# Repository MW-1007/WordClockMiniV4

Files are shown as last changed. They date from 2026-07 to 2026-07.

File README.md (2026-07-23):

# WordClock Mini V4

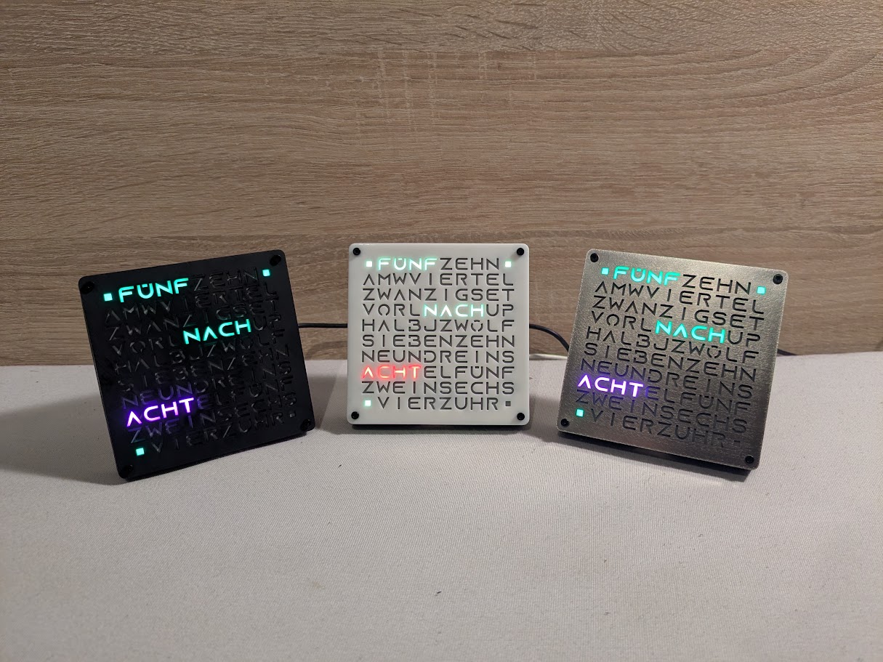
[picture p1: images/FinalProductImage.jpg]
Finished Clock


A fully custom ESP32-C3 based word clock designed and developed from scratch, including firmware, PCB design, web configuration interface, and enclosure integration.

The clock displays the current time using illuminated words in a custom designed font instead of digits and automatically synchronizes with internet time servers. Configuration is handled through a built-in responsive web interface without requiring firmware modifications.

The clock comes in 3 color variants: white, black and stainless steel





---

## Demo Videos

### Quick Demo

Quick Demo (https://github.com/user-attachments/assets/9098f4e6-2d19-4a4c-b324-8256ea519b5b)

### Making Of

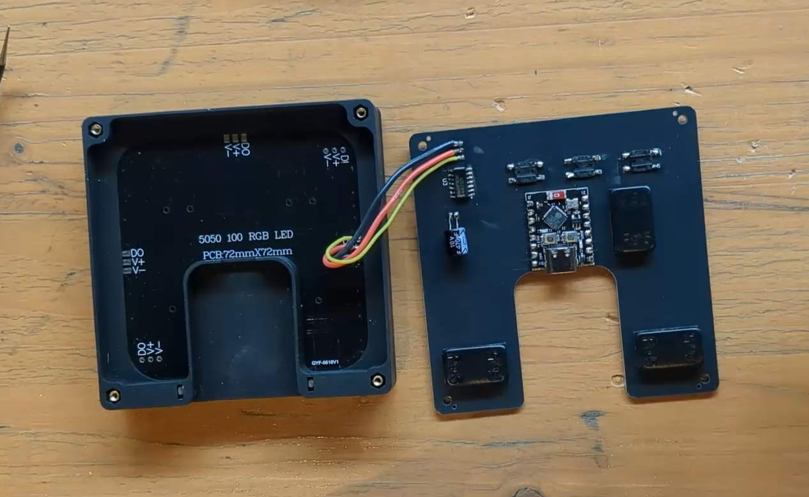
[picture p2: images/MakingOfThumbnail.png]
Making Of (https://github.com/user-attachments/assets/e9385548-6b87-468d-ab12-bdd79818bf12)


### Exploded CAD View

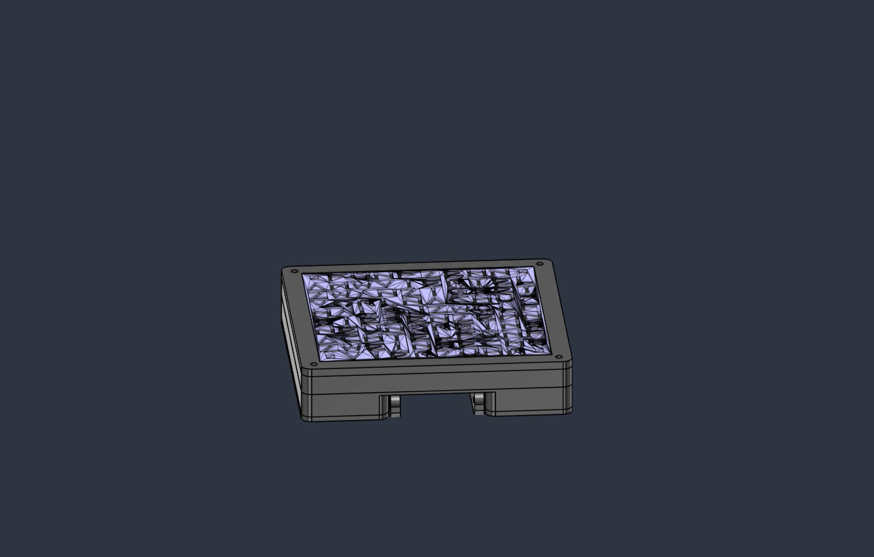
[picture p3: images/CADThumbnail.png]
CAD VIEW (https://github.com/user-attachments/assets/40dce6b3-5bbd-4252-9d69-452dc92e81c9)


---

## Gallery

### Custom PCB

<p align="center">
  PCB Front
  PCB Back
</p>

### CAD-Model built in Fusion

<p align="center">
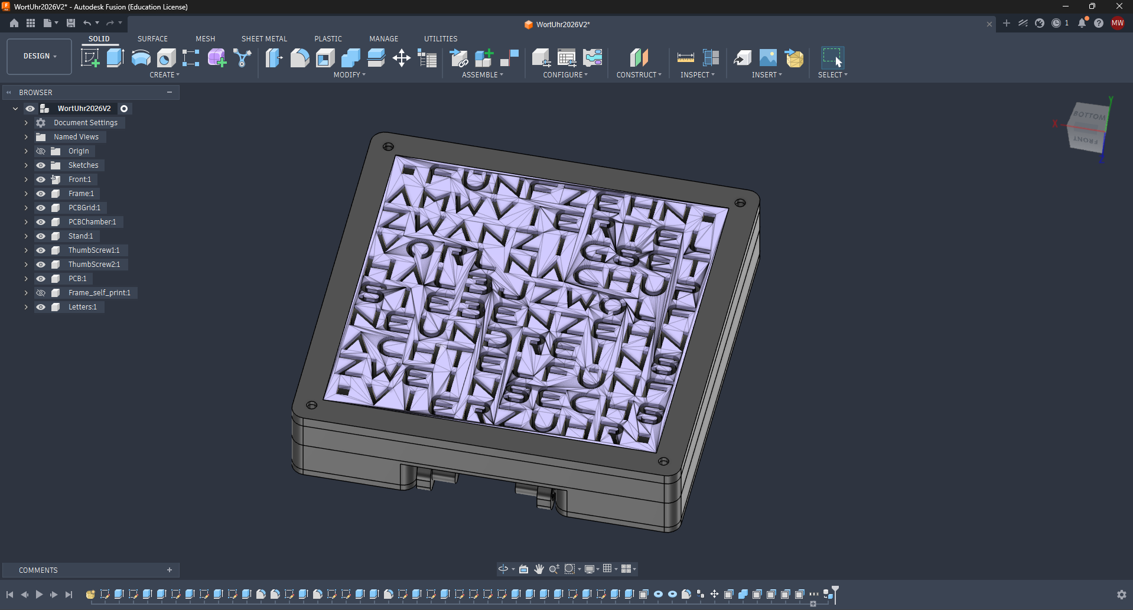
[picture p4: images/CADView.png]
CAD-Model
  
</p>

### Built-in Configuration Interface

<p align="center">
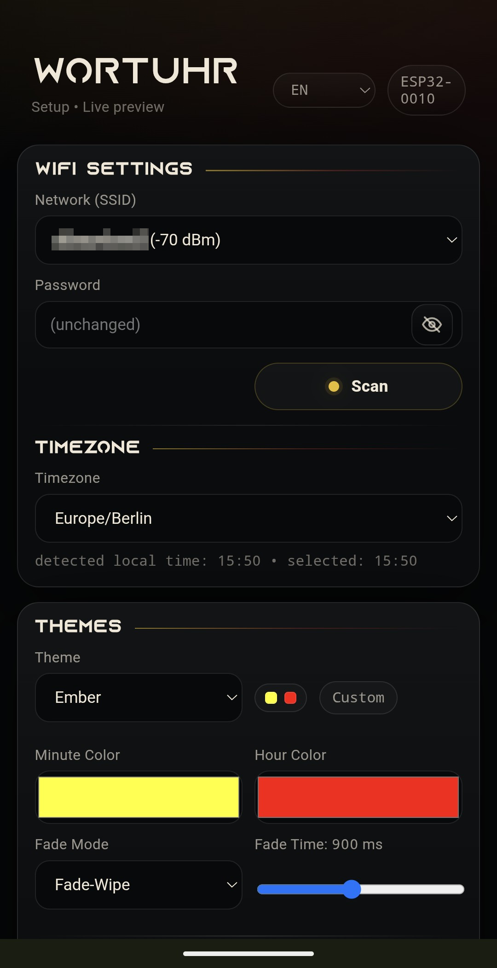
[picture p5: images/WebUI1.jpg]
WebUI
  
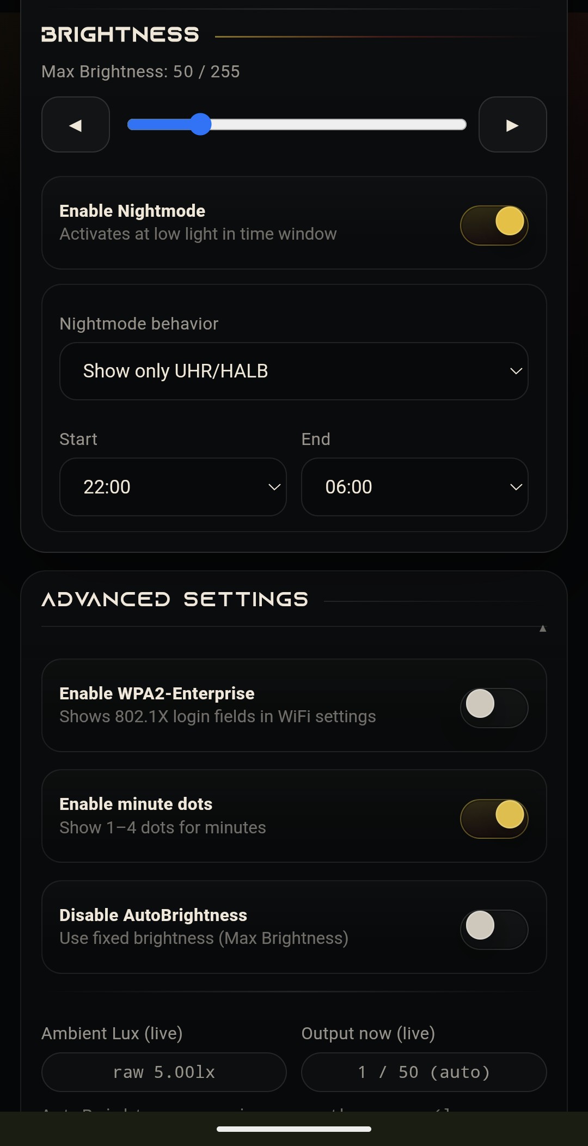
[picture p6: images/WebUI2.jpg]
WebUI
  
</p>

---

## Design Goals

The project was designed with the following goals in mind:

- Compact desktop-sized form factor
- Simple Wi-Fi based configuration / also support WPA-Enterprise
- Automatic brightness adjustment
- No dedicated mobile application required
- Wireless firmware updates
- High-quality visual appearance
- Fully custom hardware platform
- Custom packaging and user manual

---

## Features

* ESP32-C3 based architecture
* Custom PCB design
* Wi-Fi provisioning and configuration portal
* NTP time synchronization
* OTA firmware updates
* Ambient light sensing with automatic brightness control
* Multiple color themes
* Smooth LED transition animations
* Night mode
* Responsive web configuration interface

---

## Mechanical Design

The front face is manufactured using a custom stainless steel SMT stencil,
creating crisp and highly accurate lettering while maintaining a premium appearance.

The enclosure consists of multiple custom-designed 3D printed parts,
including the front frame, PCB chamber and mounting hardware.

A frosted diffuser layer is used to achieve uniform illumination
and eliminate visible LED hotspots.

---

## Hardware

| Component | Purpose |
|---|---|
| ESP32-C3 | Main microcontroller |
| WS2812 LED Matrix | Time display |
| BH1750 | Ambient light sensing |
| SN74AHCT125 | Level shifting for LED data signal |
| Custom PCB | Hardware integration |
| Frosted Diffuser | Uniform light distribution |
| 3D Printed Enclosure | Mechanical assembly |
| USB-C | Power and firmware flashing |
| Tactile Buttons | Setup and user interaction |

---

## License

This project is released under the MIT License.

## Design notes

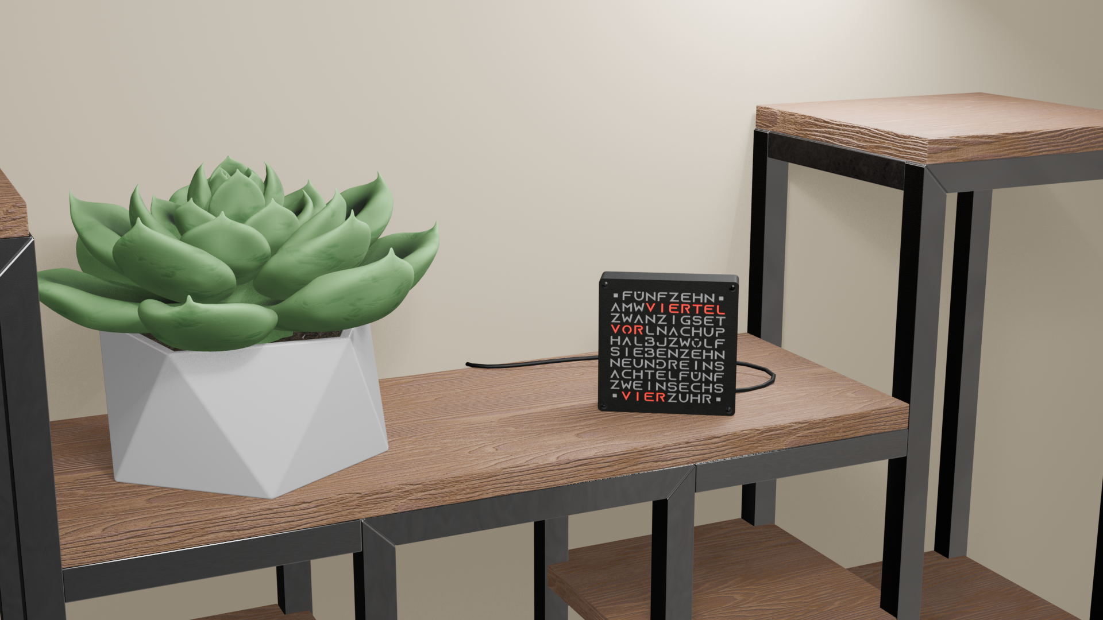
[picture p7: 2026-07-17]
images/InitialDesignRender.png

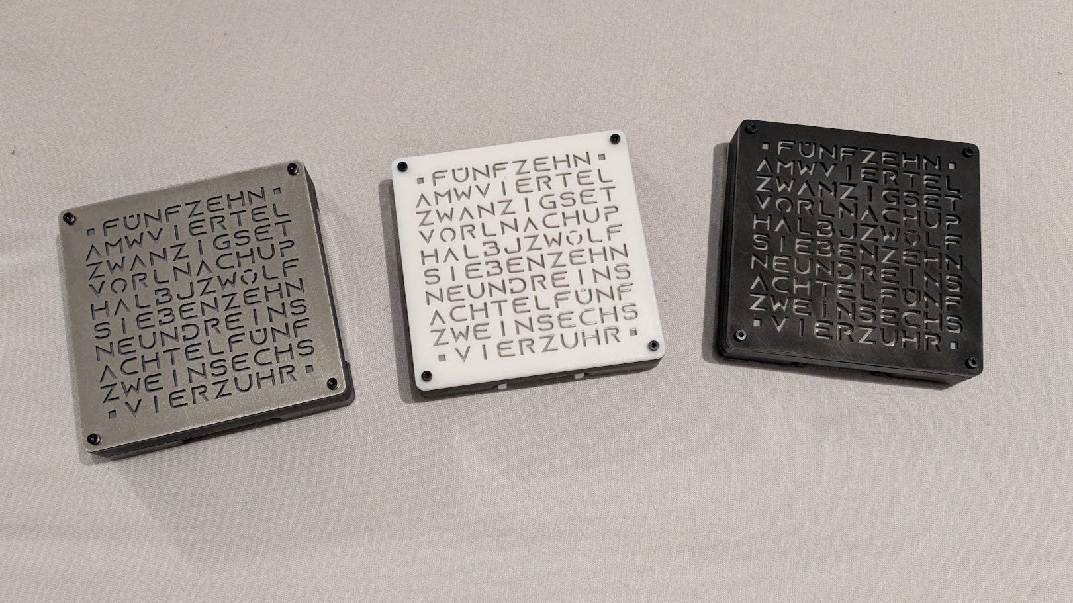
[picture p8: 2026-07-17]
images/FinalProductImage2.jpg

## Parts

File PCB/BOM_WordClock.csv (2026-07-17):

ID | Name | Designator | Footprint | Quantity | Manufacturer Part | Manufacturer | Supplier | Supplier Part | Price
1 | SN74AHCT125DR | U3 | SOIC-14_L8.7-W3.9-P1.27-LS6.0-BL | 1 | SN74AHCT125DR | TI(德州仪器) | LCSC | C155176 | 0.329
2 | TS-1095PS-A1B2-C3D2 | SW1,SW3,SW2 | KEY-SMD_4P-L6.0-W6.0-P3.90-LS9.0 | 3 | TS-1095PS-A1B2-C3D2 | Yuandi(元迪) | LCSC | C2834918 | 0.056
3 | ESP32C3-SUPERMINI | U1 | COMM-SMD_16P-L22.5-W18.0-P2.54-TL | 1 | ESP32C3-SuperMini | null | LCSC | C9900147397
4 | BH1750FVI-TR | U2 | WSOF-6_L2.6-W1.6-P0.50-TL | 1 | BH1750FVI-TR | ROHM(罗姆) | LCSC | C78960 | 0.932
5 | 100nF | C3,C4,C5,C1,C2 | C0402 | 5 | CL05B104KO5NNNC | SAMSUNG(三星) | LCSC | C1525 | 0.001
6 | 100kΩ | R7 | R0402 | 1 | 0402WGF1003TCE | UNI-ROYAL(厚声) | LCSC | C25741 | 0.001
7 | 470Ω | R1 | R0402 | 1 | 0402WGF4700TCE | UNI-ROYAL(厚声) | LCSC | C25117 | 0.001
8 | 4.7kΩ | R2,R3 | R0402 | 2 | 0402WGF4701TCE | UNI-ROYAL(厚声) | LCSC | C25900 | 0.001
9 | 10kΩ | R4,R5,R6 | R0402 | 3 | 0402WGF1002TCE | UNI-ROYAL(厚声) | LCSC | C25744 | 0.001

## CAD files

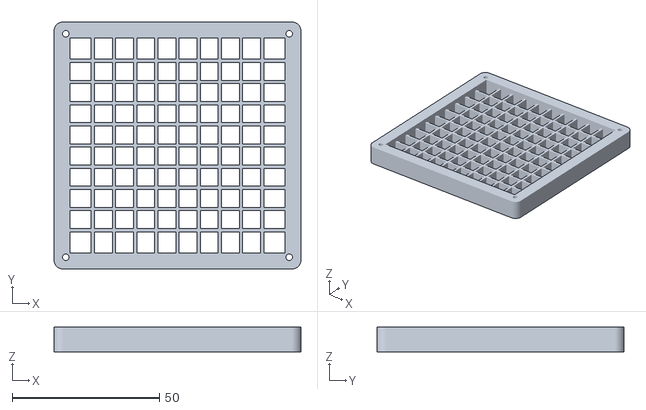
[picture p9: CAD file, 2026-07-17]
CAD/Frame_with_Grid.stl
84.0 x 84.0 x 8.50

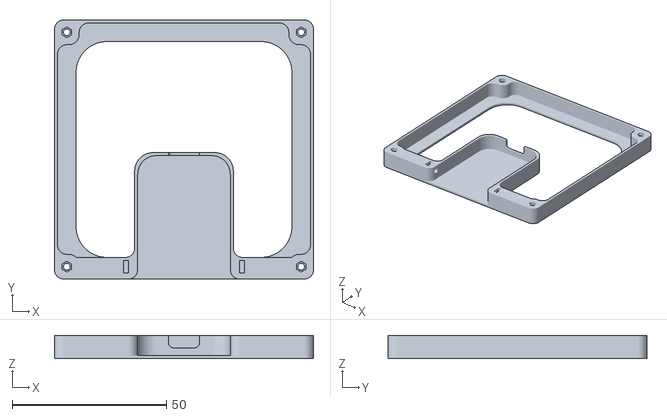
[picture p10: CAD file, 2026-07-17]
CAD/PCB_Chamber.stl
84.0 x 84.0 x 7.50

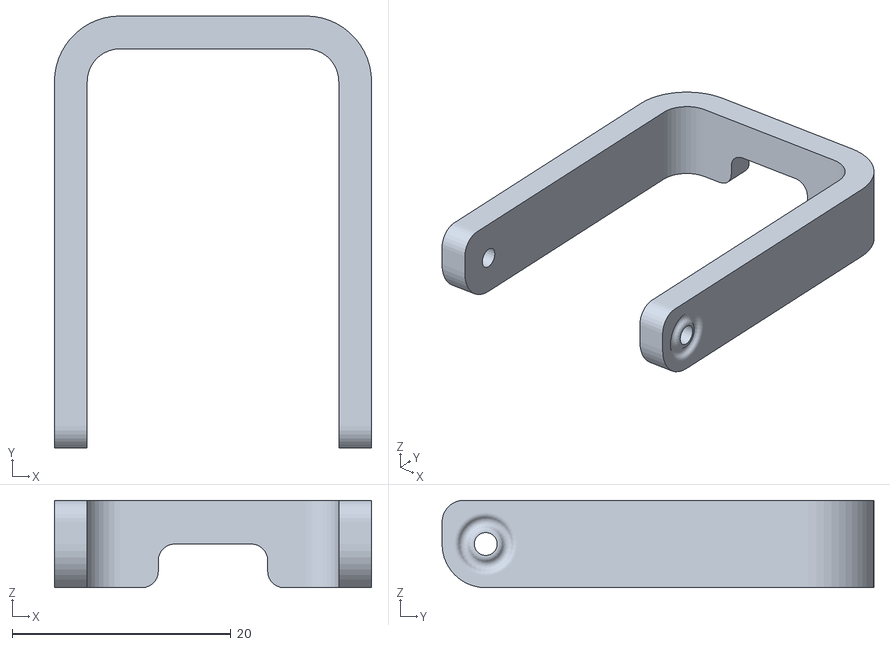
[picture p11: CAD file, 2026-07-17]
CAD/Stand.stl
29.0 x 39.5 x 8.00

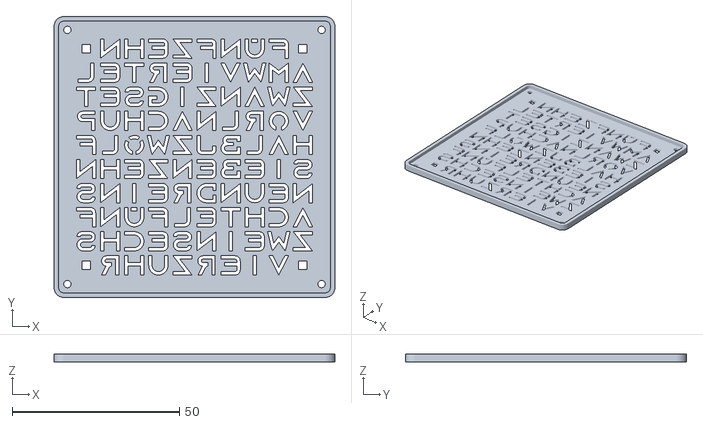
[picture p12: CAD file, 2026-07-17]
CAD/Front.stl
84.0 x 84.0 x 2.50

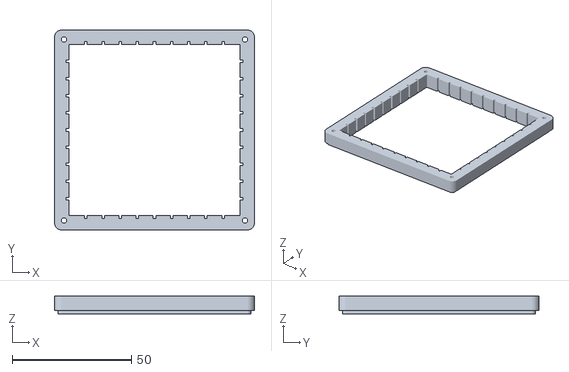
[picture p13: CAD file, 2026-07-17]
CAD/Frame.stl
84.0 x 84.0 x 7.50

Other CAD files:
CAD/WortUhr2026.blend

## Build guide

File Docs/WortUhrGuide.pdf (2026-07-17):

# WORTUHR ANLEITUNG

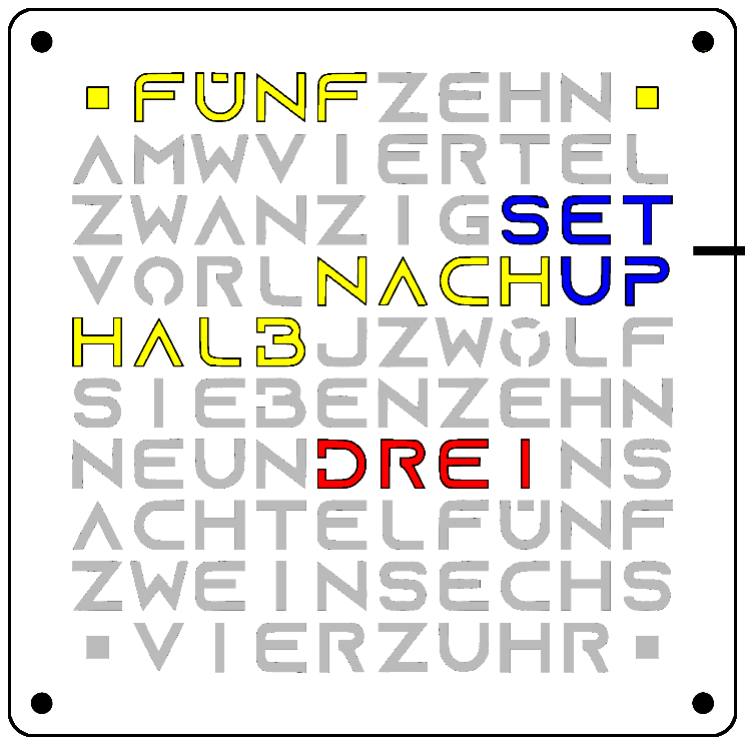
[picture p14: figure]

- Anzeige der Uhrzeit durch Wörter
- 5-minütige Genauigkeit
- Einzelne Minuten werden durch die Punkte in den Ecken signalisiert

Bsp.: FuNF NACH HALB DREI
+ 2 Punkte leuchten
→ 14:37 Uhr
- Setup-LEDs signalisieren Status
- Blau: Config-Portal ist offen
- Grün: stellt Verbindung her
- Weiß: Helligkeit anpassen
- Rot: Verbindungsfehler

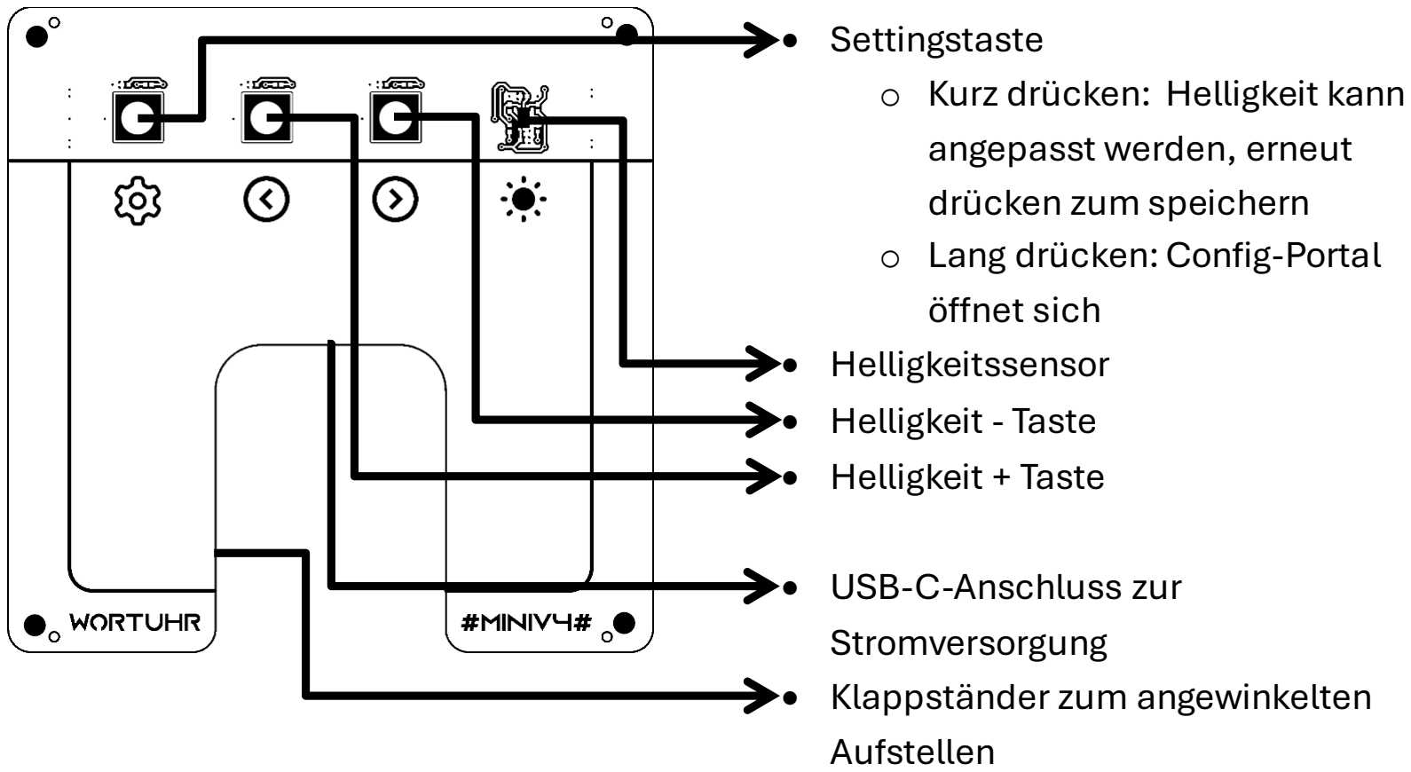
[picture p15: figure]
• Settingstaste • Kurz drücken: Helligkeit kann angepasst werden, erneut drücken zum speichern • Lang drücken:Config-Portal öffnet sich • Helligkeitssensor • Helligkeit - Taste • Helligkeit + Taste; • USB-C-Anschluss zur Stromversorgung • Klappständer zum angewinkelten Aufstellen

CONFIG | PORTAL

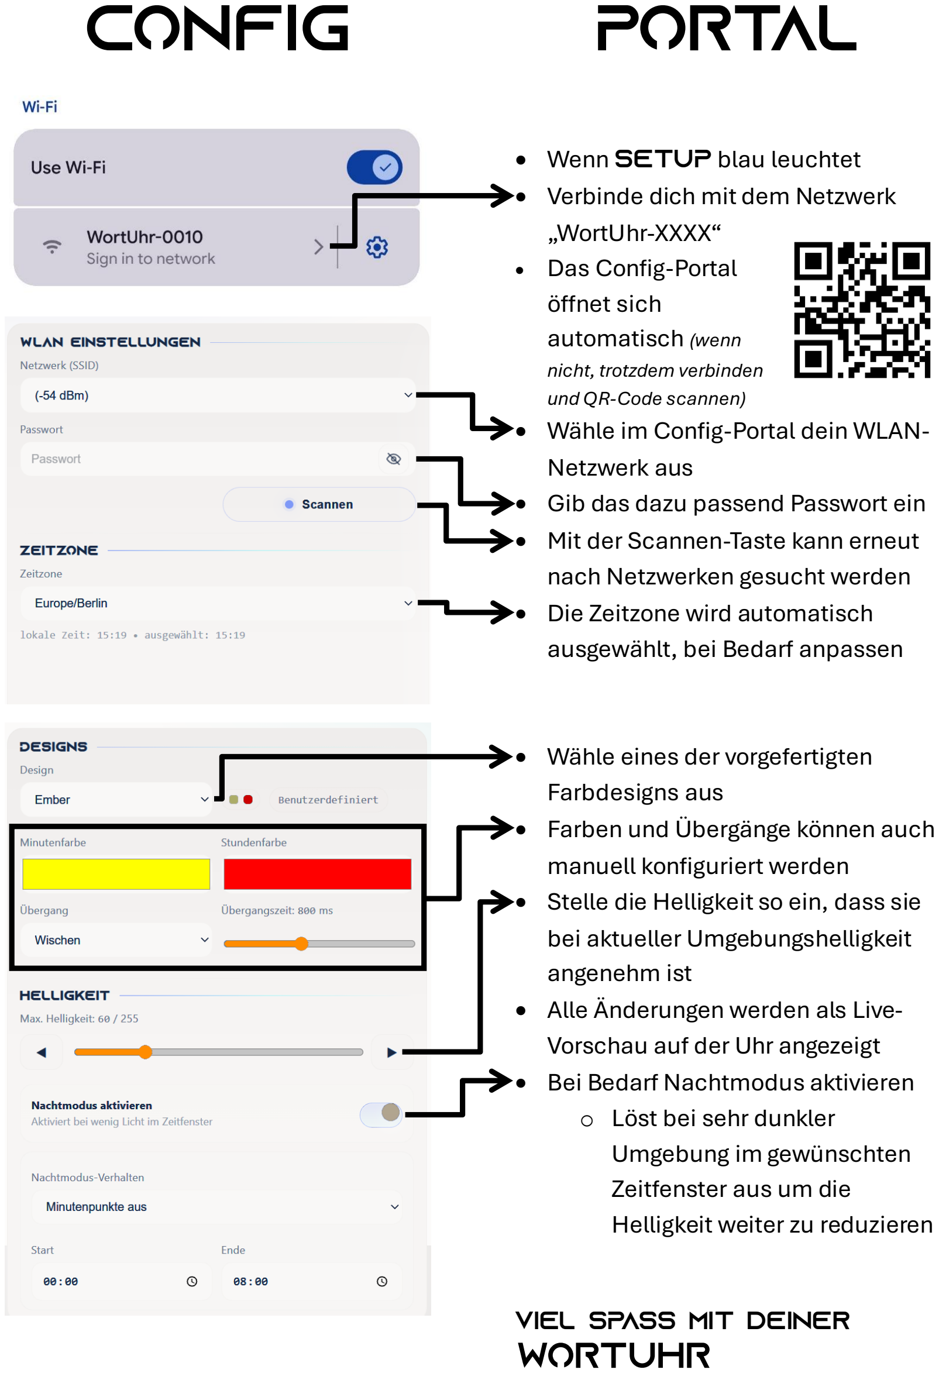
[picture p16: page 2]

- Wenn SETUP blau leuchtet
- Verbinde dich mit dem Netzwerk „WortUhr-XXXX“
- Das Config-Portal
öffnet sich
automatisch (wenn
nicht, trotzdem verbinden
und QR-Code scannen)
- Wähle im Config-Portal dein WLAN-Netzwerk aus
- Gib das dazu passend Passwort ein
- Mit der Scannen-Taste kann erneut nach Netzwerken gesucht werden
- Die Zeitzone wird automatisch ausgewählt, bei Bedarf anpassen
- Wähle eines der vorgefertigten Farbdesigns aus
- Farben und Übergänge können auch manuell konfiguriert werden
- Stelle die Helligkeit so ein, dass sie bei aktueller Umgebungshelligkeit angenehm ist
- Alle Änderungen werden als Live-Vorschau auf der Uhr angezeigt
- Bei Bedarf Nachtmodus aktivieren
- Löst bei sehr dunkler
Umgebung im gewünschten
Zeitfenster aus um die
Helligkeit weiter zu reduzieren

VIEL SPAss mit deiner
WORTUHR

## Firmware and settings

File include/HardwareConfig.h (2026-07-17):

#pragma once

#include <Arduino.h>

namespace Hardware {
constexpr uint8_t LED_PIN = 3;
constexpr uint16_t LED_COUNT = 100;

constexpr uint8_t BH1750_SDA_PIN = 0;
constexpr uint8_t BH1750_SCL_PIN = 1;
constexpr uint8_t BH1750_DVI_PIN = 4;

constexpr uint8_t BTN_SETTINGS = 5;
constexpr uint8_t BTN_RIGHT = 6;
constexpr uint8_t BTN_LEFT = 7;
}  // namespace Hardware

// Compatibility aliases used by the existing firmware implementation.
constexpr uint8_t LED_PIN = Hardware::LED_PIN;
constexpr uint16_t LED_COUNT = Hardware::LED_COUNT;
constexpr uint8_t BH1750_SDA_PIN = Hardware::BH1750_SDA_PIN;
constexpr uint8_t BH1750_SCL_PIN = Hardware::BH1750_SCL_PIN;
constexpr uint8_t BH1750_DVI_PIN = Hardware::BH1750_DVI_PIN;
constexpr uint8_t BTN_SETTINGS = Hardware::BTN_SETTINGS;
constexpr uint8_t BTN_RIGHT = Hardware::BTN_RIGHT;
constexpr uint8_t BTN_LEFT = Hardware::BTN_LEFT;

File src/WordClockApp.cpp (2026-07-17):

/**
 * @file WordClockApp.cpp
 * @brief Main application implementation for the WordClock Mini V4.
 *
 * This translation unit coordinates the complete device lifecycle:
 *
 * - persistent configuration storage in ESP32 NVS
 * - Wi-Fi provisioning for WPA2-Personal and WPA2-Enterprise networks
 * - NTP synchronization and timezone handling
 * - a captive configuration portal with live LED preview
 * - OTA firmware updates through ElegantOTA
 * - word-clock rendering on a 10 x 10 WS2812 LED matrix
 * - gamma-corrected frame transitions and brightness fades
 * - BH1750 ambient-light measurements and automatic brightness control
 * - configurable night mode behaviour
 * - button handling, deep sleep and timed wake-up
 *
 * The implementation is intentionally kept behind the small public interface
 * declared in WordClockApp.h. PlatformIO calls wordClockSetup() and
 * wordClockLoop() from src/main.cpp.
 *
 * @note Wi-Fi credentials and application settings are stored separately in
 *       NVS namespaces named "wifi" and "wordclk".
 * @note WPA2-Enterprise is currently configured without CA certificate
 *       validation. This is convenient for some institutional networks, but
 *       it does not authenticate the network's identity.
 */

#include <Arduino.h>
#include "HardwareConfig.h"
#include "TimezoneMapper.h"
#include "WordClockApp.h"
#include <Adafruit_NeoPixel.h>
#include <Preferences.h>
#include <WiFi.h>
#include <WebServer.h>
#include <DNSServer.h>
#include <time.h>
#include "esp_sntp.h"
#include <esp_sleep.h>
#include <string.h>
#include <math.h>
#include <Wire.h>
#include <driver/gpio.h>

#include "esp_wifi.h"
#if __has_include("esp_eap_client.h")
  #include "esp_eap_client.h"
#else
  #include "esp_wpa2.h"
#endif

#include <ElegantOTA.h>

#include "wordclock_font.h"   // contains wordclock_woff2 + len
#include "page_html.h"        // contains PAGE_HTML PROGMEM

// -------------------- Hardware --------------------
/**
 * Global NeoPixel driver for the physical 10 x 10 display.
 *
 * Frame buffers in this file store colors in the same packed format returned
 * by Adafruit_NeoPixel::Color(). Brightness is applied in software before a
 * frame is transferred to the strip.
 */
Adafruit_NeoPixel strip(LED_COUNT, LED_PIN, NEO_GRB + NEO_KHZ800);

// -------------------- Persistent application settings --------------------
/**
 * Available frame transition strategies.
 *
 * FADE_OFF updates the target frame immediately. FADE_2PHASE first removes
 * obsolete words and then introduces new words. FADE_CROSS interpolates the
 * complete frame, while FADE_WIPE staggers the transition by matrix column.
 */
enum FadeMode : uint8_t { FADE_OFF = 0, FADE_2PHASE = 1, FADE_CROSS = 2, FADE_WIPE = 3 };

/**
 * Reduced-display behaviour used while night mode is active.
 *
 * NM_DOTS_ONLY keeps the normal words but suppresses the four minute dots.
 * NM_HALF_HOUR_ONLY reduces the displayed time to full and half hours.
 * NM_NOTHING turns the display off completely.
 */
enum NightModeBehavior : uint8_t { NM_DOTS_ONLY = 0, NM_HALF_HOUR_ONLY = 1 , NM_NOTHING = 2 };

static const uint32_t CFG_MAGIC   = 0x57434C4B; // 'WCLK'
static const uint16_t CFG_VERSION = 10;

/**
 * @brief Versioned configuration persisted as a binary blob in NVS.
 *
 * CFG_MAGIC detects unrelated or corrupt data, while CFG_VERSION invalidates
 * layouts from older firmware revisions. Whenever this structure changes,
 * CFG_VERSION must be incremented because the stored byte layout changes.
 */
struct Settings {
  uint32_t magic;
  uint16_t version;

  // Basic
  uint8_t  maxBrightness;         // 1..255
  uint8_t  disableAutoBrightness; // 0/1 (0 = AutoBrightness AN)
  uint8_t  fadeMode;              // FadeMode
  uint16_t fadeMs;                // 0..2000ms (step 100)
  uint32_t colorM;                // 0xRRGGBB
  uint32_t colorH;                // 0xRRGGBB
  char     tzName[32];            // IANA

  // Nightmode (Basic)
  uint8_t  enableNightmode;       // 0/1
  uint8_t  nightBehavior;         // NightModeBehavior
  uint16_t nightStartMin;         // minutes since 00:00 (0..1439)
  uint16_t nightEndMin;           // minutes since 00:00 (0..1439)

  // Advanced
  uint32_t bootColor;             // SETUP (Portal/NoCreds)
  uint16_t bootFadeMs;

  uint32_t connectColor;          // SETUP (connecting)
  uint16_t connectPulseMs;        // pulse period ms

  uint8_t  ntpSyncHours;
  uint8_t  connectionTimeoutSec;
  uint8_t  enableMinuteDots;
  uint16_t stepMs;                // animation step

  // AutoBrightness tuning (Advanced)
  uint16_t luxCheckIntervalSec;   // 1..60
  uint8_t  hysteresisDelta;       // 1..50 (used 1:1 for brightness + nightmode hysteresis)
  uint32_t portalInactiveMaxSec;  // 30..3600

  float luxMin;
  float luxMax;

  // Nightmode tuning (Advanced)
  float    nightLuxThreshold;     // lux threshold for nightmode activation
};

static Settings cfg;
static Preferences prefsCfg;
static Preferences prefsWifi;

// -------------------- Wi-Fi credentials (PSK vs Enterprise) --------------------
/**
 * Credentials are stored separately from display settings so network changes
 * do not affect the versioned Settings binary layout.
 */
enum WifiMode : uint8_t { WIFI_MODE_PSK = 0, WIFI_MODE_ENTERPRISE = 1 };

/**
 * @brief Runtime representation of either WPA2-Personal or WPA2-Enterprise
 *        credentials.
 *
 * Passwords are never returned by the configuration API. Empty password fields
 * submitted by the portal may reuse an existing saved password for the same
 * SSID and authentication mode.
 */
struct WifiCreds {
  WifiMode mode = WIFI_MODE_PSK;
  String ssid;

  // PSK
  String psk;

  // Enterprise (PEAP/MSCHAPv2 typical)
  String eapIdentity; // outer identity (optional; fallback to eapUser)
  String eapUser;     // inner username
  String eapPass;     // password
};

static bool loadWifiCredsEx(WifiCreds &out) {
  prefsWifi.begin("wifi", true);

  out.mode = (WifiMode)prefsWifi.getUChar("mode", (uint8_t)WIFI_MODE_PSK);
  out.ssid = prefsWifi.getString("ssid", "");

  // Keep your old key names for compatibility:
  out.psk        = prefsWifi.getString("pass", "");
  out.eapIdentity= prefsWifi.getString("eap_id", "");
  out.eapUser    = prefsWifi.getString("eap_user", "");
  out.eapPass    = prefsWifi.getString("eap_pass", "");

  prefsWifi.end();
  return out.ssid.length() > 0;
}

static void saveWifiCredsEx(const WifiCreds &in) {
  prefsWifi.begin("wifi", false);

  prefsWifi.putUChar("mode", (uint8_t)in.mode);
  prefsWifi.putString("ssid", in.ssid);

  // PSK
  prefsWifi.putString("pass", in.psk);

  // Enterprise
  prefsWifi.putString("eap_id", in.eapIdentity);
  prefsWifi.putString("eap_user", in.eapUser);
  prefsWifi.putString("eap_pass", in.eapPass);

  prefsWifi.end();
}
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

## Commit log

2026-07-17 initial documentation commit
    added all necessary Code, CAD, PCB, font and guide files
    [BOM_WordClock.csv, Frame.stl, Frame_with_Grid.stl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]
2026-07-23 added CAD to images and README.md

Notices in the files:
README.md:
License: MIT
